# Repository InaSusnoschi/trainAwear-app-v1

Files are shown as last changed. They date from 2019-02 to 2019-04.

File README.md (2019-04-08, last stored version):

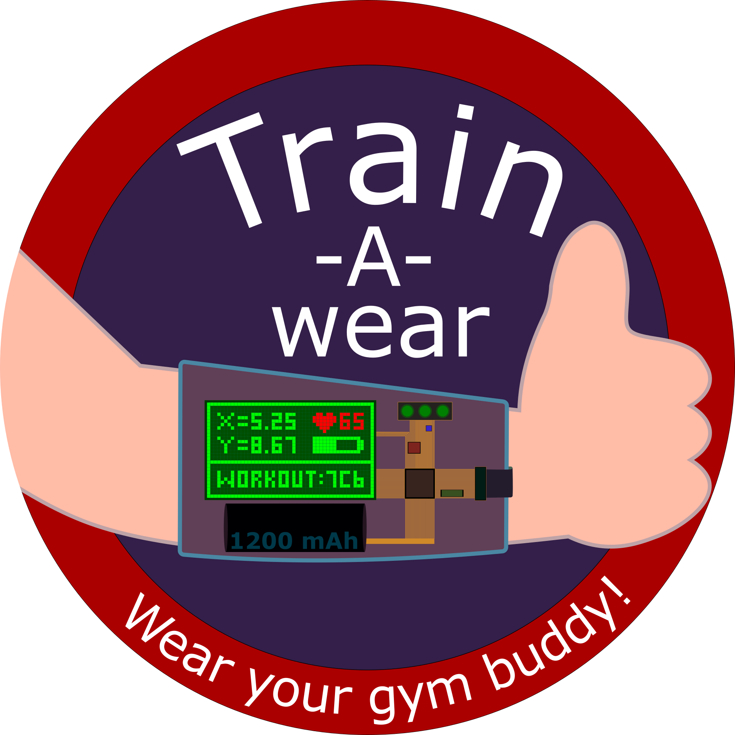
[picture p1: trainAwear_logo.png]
train-A-wear logo


## Train-A-Wear
### A wearable workout monitor that provides real time feedback on the user's form while performing basic workouts to improve shape and exercise outcomes.

This uses a Raspberry Pi and three Inertial Measurement Units that detect position and orientation of the body segments they are placed on.

## Prerequisites
Inertial Measurement Unit train-box

### Android app:
<ul>
  <li> Android SDK 27 </li>
  <li> Android Build tools v27.0.2 </li>
  <li> Android Support Repository </li>
  <li> compile 'com.synnapps:carouselview:0.1.5' in Gradle file</>
</ul>

## Installing

## Documentation

### Examples
Using IMU data to obtain body position and orientation.

Decision loops for workout feedback.

Real time data plotting on smartphone (php)

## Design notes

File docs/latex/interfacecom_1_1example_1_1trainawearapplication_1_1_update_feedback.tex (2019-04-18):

\hypertarget{interfacecom_1_1example_1_1trainawearapplication_1_1_update_feedback}{}\section{com.\+example.\+trainawearapplication.\+Update\+Feedback Interface Reference}
\label{interfacecom_1_1example_1_1trainawearapplication_1_1_update_feedback}\index{com.example.trainawearapplication.UpdateFeedback@{com.example.trainawearapplication.UpdateFeedback}}

Inheritance diagram for com.\+example.\+trainawearapplication.\+Update\+Feedback\+:
\nopagebreak
\begin{figure}[H]
\begin{center}
\leavevmode
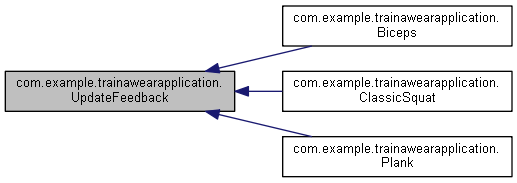
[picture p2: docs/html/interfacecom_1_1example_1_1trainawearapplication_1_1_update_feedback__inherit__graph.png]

\end{center}
\end{figure}
\subsection*{Public Member Functions}
\begin{DoxyCompactItemize}
\item 
void \mbox{\hyperlink{interfacecom_1_1example_1_1trainawearapplication_1_1_update_feedback_a7a026880188b11aca6d8184d57e699e8}{set\+View\+Text}} (Text\+View view, String text)
\end{DoxyCompactItemize}

\subsection{Detailed Description}

Definition at line 10 of file Update\+Feedback.\+java.

\subsection{Member Function Documentation}
\mbox{\Hypertarget{interfacecom_1_1example_1_1trainawearapplication_1_1_update_feedback_a7a026880188b11aca6d8184d57e699e8}\label{interfacecom_1_1example_1_1trainawearapplication_1_1_update_feedback_a7a026880188b11aca6d8184d57e699e8}} 
\index{com.example.trainawearapplication.UpdateFeedback@{com.example.trainawearapplication.UpdateFeedback}!setViewText@{setViewText}}
\index{setViewText@{setViewText}!com.example.trainawearapplication.UpdateFeedback@{com.example.trainawearapplication.UpdateFeedback}}
\subsubsection{\texorpdfstring{setViewText()}{setViewText()}}
{\footnotesize\ttfamily void com.\+example.\+trainawearapplication.\+Update\+Feedback.\+set\+View\+Text (\begin{DoxyParamCaption}\item[{Text\+View}]{view,  }\item[{String}]{text }\end{DoxyParamCaption})}

Implemented in \mbox{\hyperlink{classcom_1_1example_1_1trainawearapplication_1_1_classic_squat_ab193e39e2f1255fd88d0508cfe7a63ff}{com.\+example.\+trainawearapplication.\+Classic\+Squat}}, \mbox{\hyperlink{classcom_1_1example_1_1trainawearapplication_1_1_plank_a4d4a46b71ced8fe89023ccbf14d17f77}{com.\+example.\+trainawearapplication.\+Plank}}, and \mbox{\hyperlink{classcom_1_1example_1_1trainawearapplication_1_1_biceps_a6e1ab1b99cd05b29fb7346b0642b7d0e}{com.\+example.\+trainawearapplication.\+Biceps}}.

The documentation for this interface was generated from the following file\+:\begin{DoxyCompactItemize}
\item 
D\+:/cloned repo trainawear/train-\/\+A-\/wear/\+Phone App/app/src/main/java/com/example/trainawearapplication/\mbox{\hyperlink{_update_feedback_8java}{Update\+Feedback.\+java}}\end{DoxyCompactItemize}

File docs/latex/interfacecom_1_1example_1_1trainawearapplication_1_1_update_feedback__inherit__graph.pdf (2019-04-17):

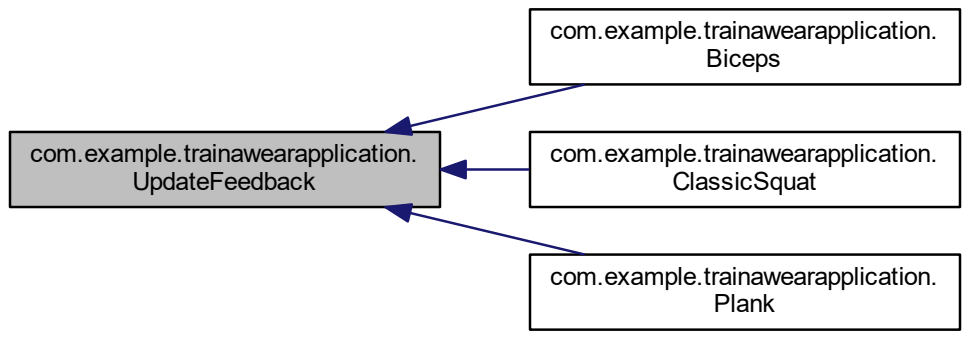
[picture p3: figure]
com.example.trainawearapplication. UpdateFeedback; com.example.trainawearapplication. Biceps; com.example.trainawearapplication. ClassicSquat; com.example.trainawearapplication. Plank

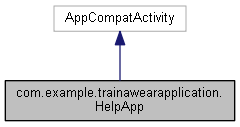
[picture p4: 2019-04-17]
docs/html/classcom_1_1example_1_1trainawearapplication_1_1_help_app__inherit__graph.png

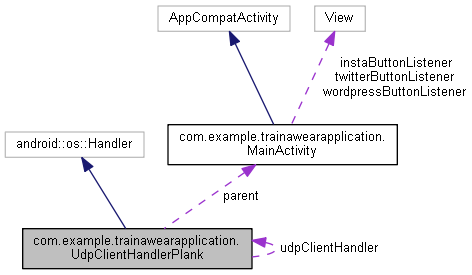
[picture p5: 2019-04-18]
docs/html/classcom_1_1example_1_1trainawearapplication_1_1_udp_client_handler_plank__coll__graph.png

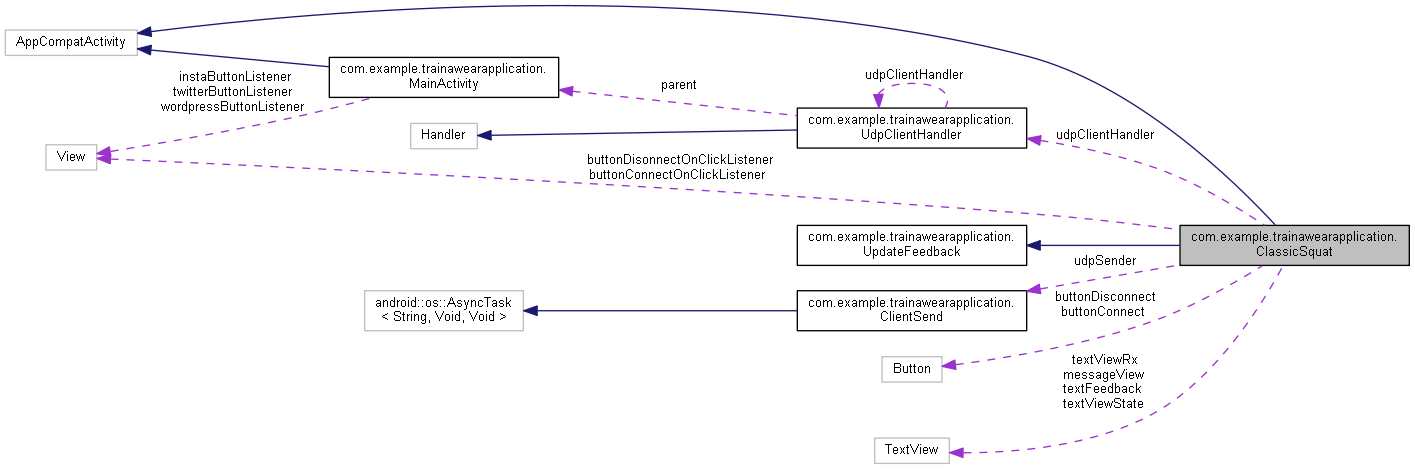
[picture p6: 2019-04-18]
docs/html/classcom_1_1example_1_1trainawearapplication_1_1_classic_squat__coll__graph.png

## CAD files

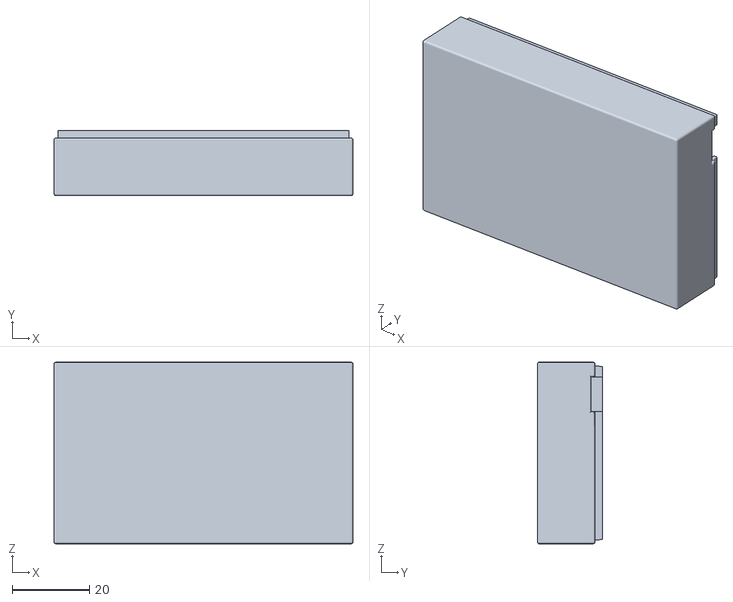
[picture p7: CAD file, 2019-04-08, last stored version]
Hardware/Sensor-Box/box-base-1.stl
77.7 x 17.0 x 47.2

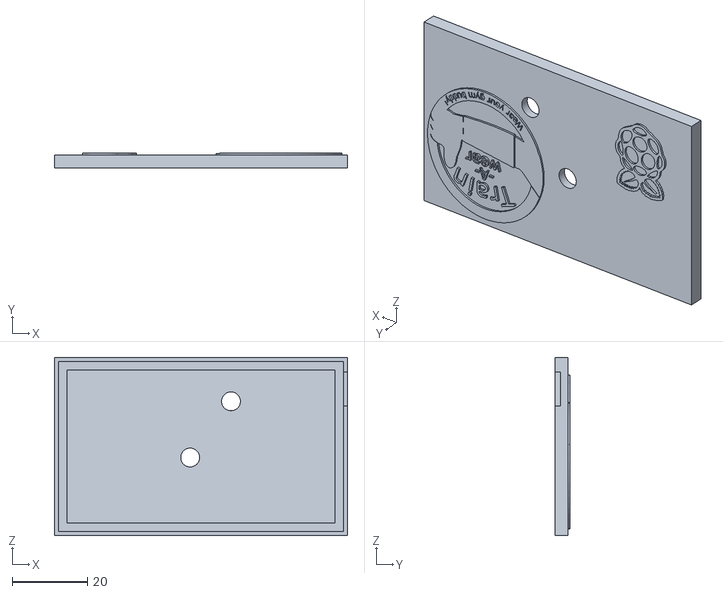
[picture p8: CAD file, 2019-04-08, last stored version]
Hardware/Sensor-Box/box-top-1.stl
77.7 x 4.00 x 47.2

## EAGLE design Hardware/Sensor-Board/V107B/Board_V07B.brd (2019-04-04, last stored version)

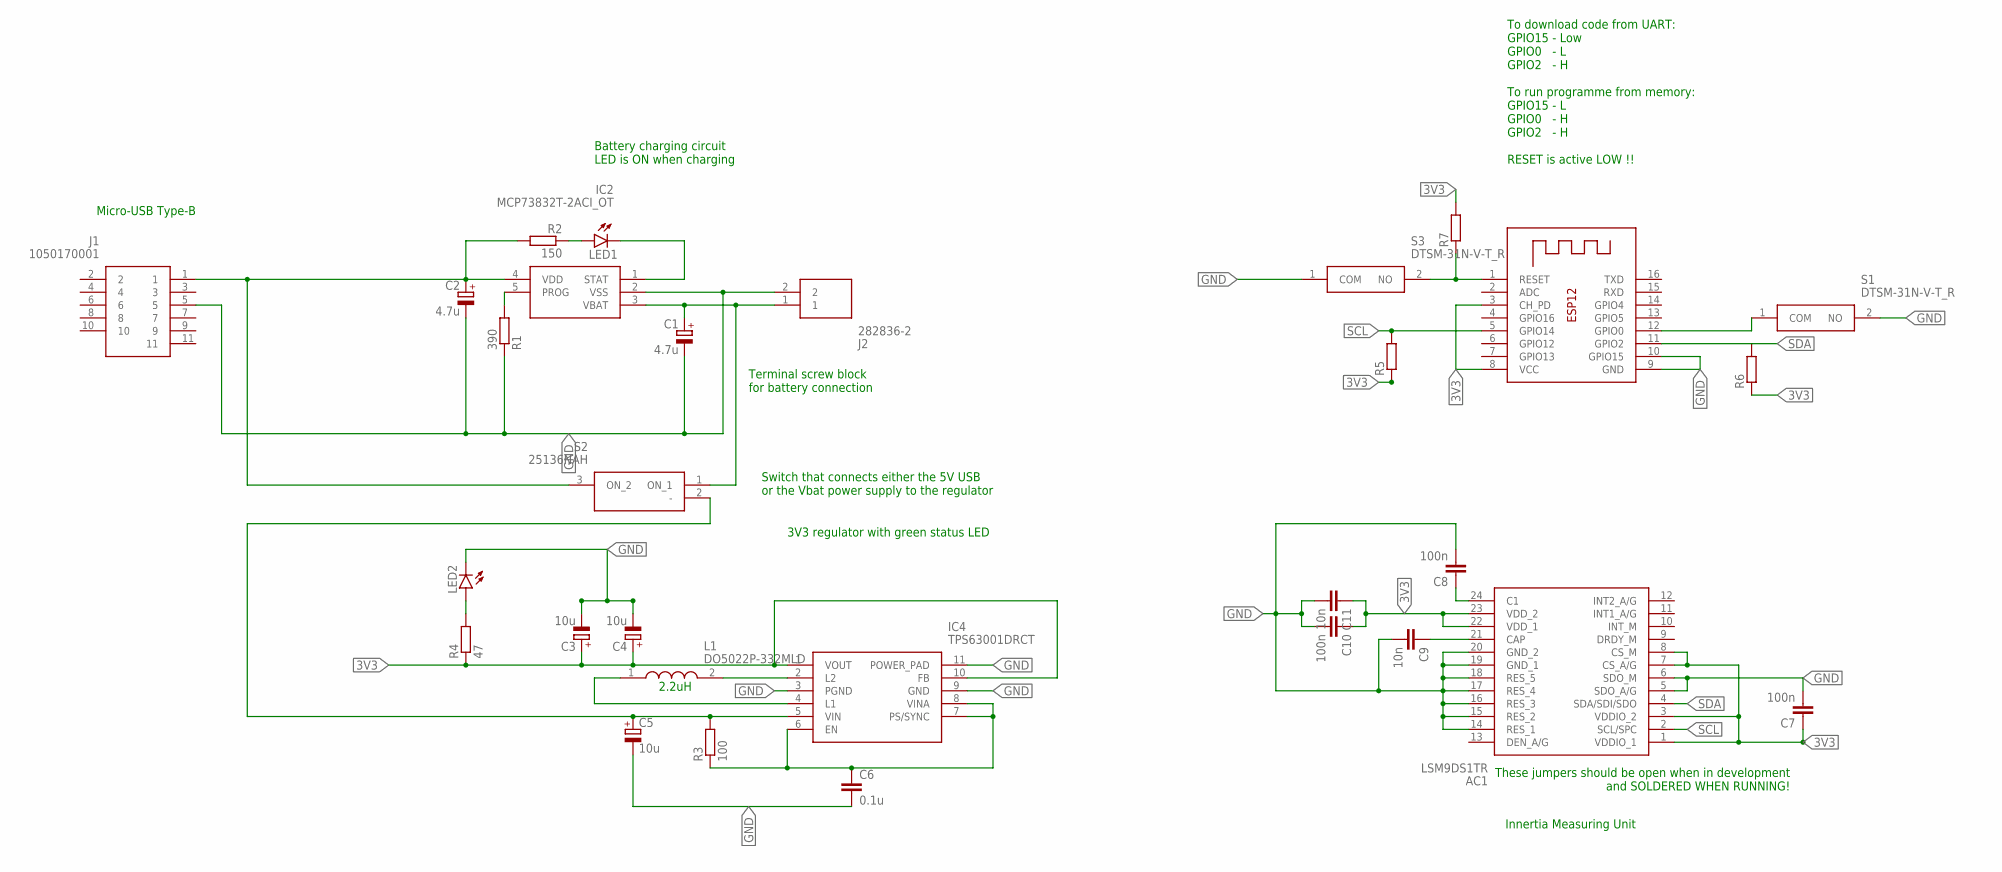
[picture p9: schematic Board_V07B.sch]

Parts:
AC1: LSM9DS1TR; LGA-24L(3X3.5X1MM)
C1, C2: 4.7u; D/7343-31R
C3, C4, C5: 10u; D/7343-31R
C6: 0.1u; C0402
C7, C8, C10: 100n; C0805
C9, C11: 10n; C0805
IC2: MCP73832T-2ACI_OT; SOT95P270X145-5N
IC4: TPS63001DRCT; SON50P300X300X100-11N
J1: 1050170001; MICROUSB-BTYPE
J2: 282836-2; SHDR2W100P0X500_1X2_1000X820X1
L1: DO5022P-332MLD; DO5022P-104MLD
LED1, LED2: LED5MM
R1: 390; R0805
R2: 150; R0805
R3: 100; R0805
R4: 47; R0805
R5, R6, R7: R-EU_R0805; R0805
S1, S3: DTSM-31N-V-T_R; DTSM32NVTR
S2: 25136NAH
X1: ESP-12

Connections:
3V3: AC1.1 (VDDIO_1), AC1.3 (VDDIO_2), AC1.7 (CS_A/G), AC1.8 (CS_M), AC1.22 (VDD_1), AC1.23 (VDD_2), C3.+, C4.+, C7.1, C10.1, C11.1, IC4.1 (VOUT), IC4.10 (FB), R4.1, R5.1, R6.1, R7.2, X1.3 (CH_PD), X1.8 (VCC)
5V: C2.+, IC2.4 (VDD), J1.1, R2.2, S2.3 (ON_2)
GND: AC1.5 (SDO_A/G), AC1.6 (SDO_M), AC1.14 (RES_1), AC1.15 (RES_2), AC1.16 (RES_3), AC1.17 (RES_4), AC1.18 (RES_5), AC1.19 (GND_1), AC1.20 (GND_2), C1.-, C2.-, C3.-, C4.-, C5.-, C6.2, C7.2, C8.2, C9.2, C10.2, C11.2, IC2.2 (VSS), IC4.3 (PGND), IC4.9 (GND), IC4.11 (POWER_PAD), J1.5, J2.2, LED2.K (C), R1.1, S1.2 (NO), S3.1 (COM), X1.9 (GND), X1.10 (GPIO15)
unnamed: IC2.5 (PROG), R1.2
unnamed: LED1.A, R2.1
unnamed: AC1.21 (CAP), C9.1
unnamed: C5.+, IC4.5 (VIN), R3.2, S2.2 (-)
unnamed: LED2.A, R4.2
unnamed: IC4.2 (L2), L1.2
unnamed: IC4.4 (L1), L1.1
unnamed: C6.1, IC4.6 (EN), IC4.7 (PS/SYNC), IC4.8 (VINA), R3.1
unnamed: AC1.24 (C1), C8.1
unnamed: S1.1 (COM), X1.12 (GPIO0)
unnamed: R7.1, S3.2 (NO), X1.1 (RESET)
SCL: AC1.2 (SCL/SPC), R5.2, X1.5 (GPIO14)
SDA: AC1.4 (SDA/SDI/SDO), R6.2, X1.11 (GPIO2)
STAT: IC2.1 (STAT), LED1.K (C)
VBAT: C1.+, IC2.3 (VBAT), J2.1, S2.1 (ON_1)

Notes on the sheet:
Micro-USB Type-B
Battery charging circuit LED is ON when charging
Terminal screw block for battery connection
3V3 regulator with green status LED
Switch that connects either the 5V USB or the Vbat power supply to the regulator
Innertia Measuring Unit
These jumpers should be open when in development and SOLDERED WHEN RUNNING!
2.2uH
To download code from UART: GPIO15 - Low GPIO0 - L GPIO2 - H To run programme from memory: GPIO15 - L GPIO0 - H GPIO2 - H RESET is active LOW !!

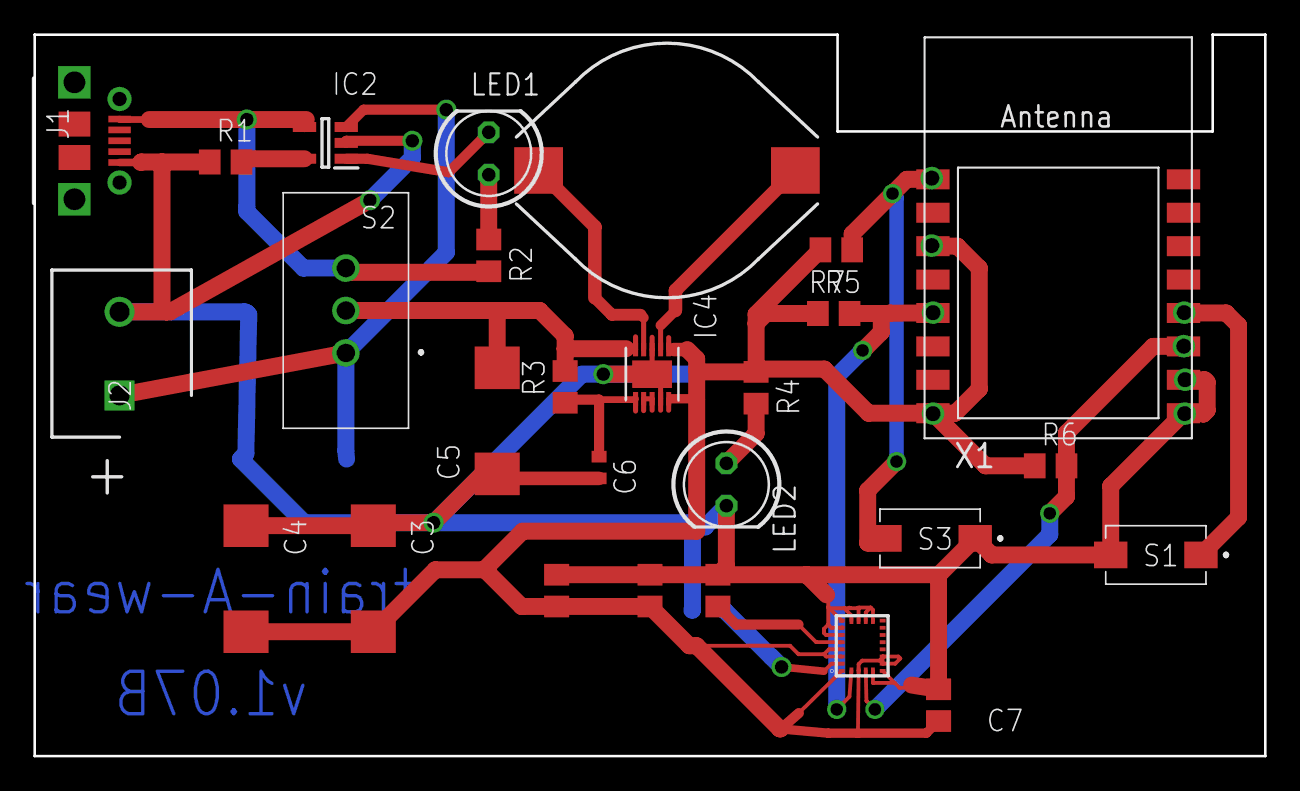
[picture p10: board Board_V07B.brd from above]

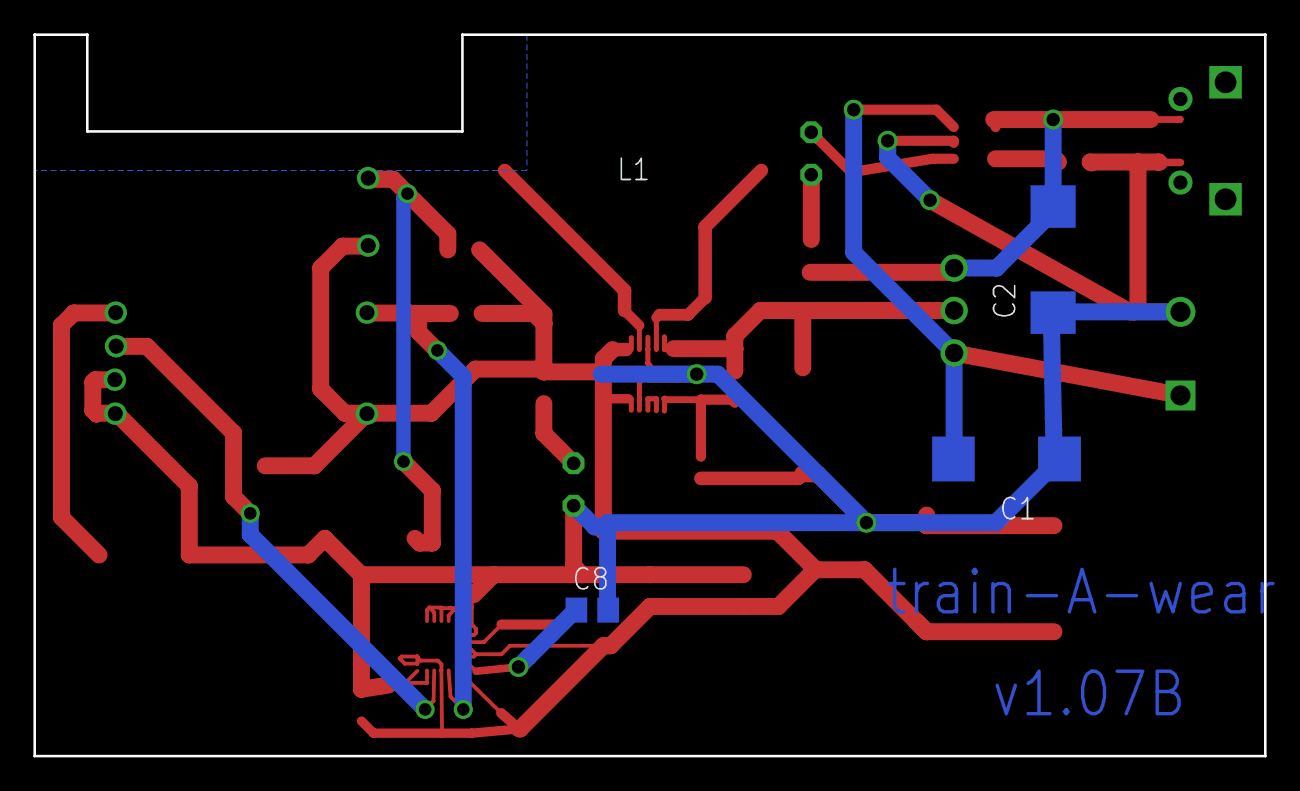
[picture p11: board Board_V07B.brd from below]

Board: 2 copper layers, 73.7 x 43.2 mm, 30 parts (3 on the bottom side), 18 nets.

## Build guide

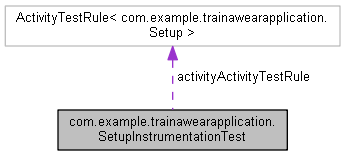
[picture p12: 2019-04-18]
docs/html/classcom_1_1example_1_1trainawearapplication_1_1_setup_instrumentation_test__coll__graph.png

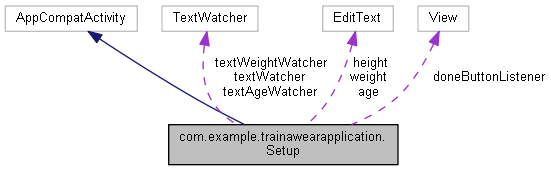
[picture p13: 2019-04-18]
docs/html/classcom_1_1example_1_1trainawearapplication_1_1_setup__coll__graph.png

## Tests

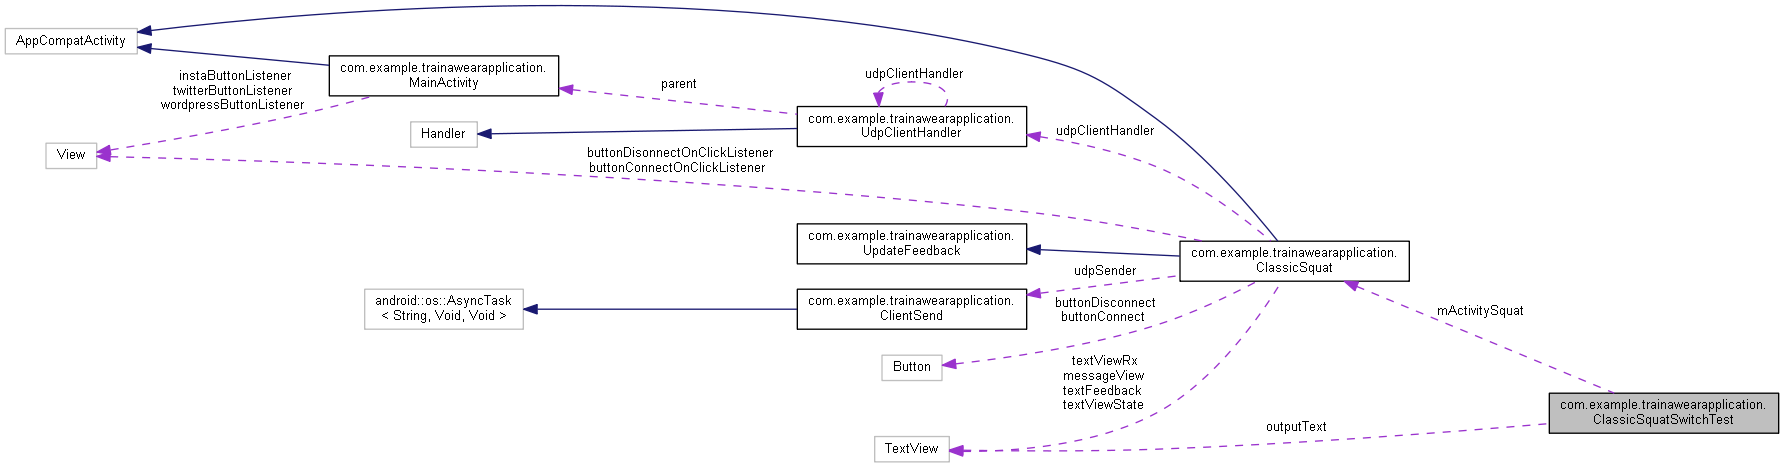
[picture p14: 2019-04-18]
docs/html/classcom_1_1example_1_1trainawearapplication_1_1_classic_squat_switch_test__coll__graph.png

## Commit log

2019-01-30 Uploading the presentation for the pitch
2019-02-19 Add files via upload
    A sample of how to use the sensors to get personalised feedback on your squats
2019-03-01 Added initial schematics and PCB for board version 1.2
    [Board_V02.brd, Board_V02.sch]
2019-03-01 Added images for the schematic and PCB to facilitate inspection on systems without appropriate software.
2019-03-01 Added V1.03 for the hardware of the sensor.
    [Board_V03.brd, Board_V03.sch]
2019-03-01 Added version 1.4 of the board along with hand-traced PCB.
    [Board_V04.brd, Board_V04.sch]
2019-03-01 Added latest hardware version - 1.05 which has also been manufactured.
    [Board_V05.brd, Board_V05.sch]
2019-03-01 Added PCB image to description 1.05
2019-03-01 Added schematic image too to the readme for V105.
2019-03-02 Added Bill of Materials for current board version.
2019-03-02 Added datasheets for all ICs on the board and microUSB connector.
2019-03-06 Add files via upload
    Side view soldering the IMU (microscope 40X)
2019-04-04 Added datasheets for the two new microcontrollers to be used for the sensor.
2019-04-04 Added next board version based on WROOM-02. Removed programming headers for simplicity of the board and added holes for P&P capability of the mcu.
    [Board_V07A.brd, Board_V07A.sch]
2019-04-04 Added board based on ESP8266 module ESP-12.
    [Board_V07B.brd, Board_V07B.sch]
2019-04-06 Added initial software skeleton for the sensor microcontroller code. Based on Arduino dev environment and not on pure toolchain.
2019-04-08 Added STL files for the sensor box by Maggie.
    [box-base-1.stl, box-top-1.stl]
2019-04-08 Modified serial speed to match the speed of the debug serial so there is no need to switch between them.
2019-04-09 Sensor software now waits for server transmission to identify server IP address. SendUDP tested nand working!
2019-04-10 Added an extra print line for easier debugging.
2019-04-10 AI-3.3 <ioana@DESKTOP-HQ4826F Overwrite remote https://github.com/InaSusnoschi/train-A-wear.git to local
    [Board_V02.brd, Board_V02.sch, Board_V03.brd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]
